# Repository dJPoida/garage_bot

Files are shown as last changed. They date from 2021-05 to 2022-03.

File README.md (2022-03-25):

# GarageBot v1.0
This project adds some form of IoT capability to my existing garage door.

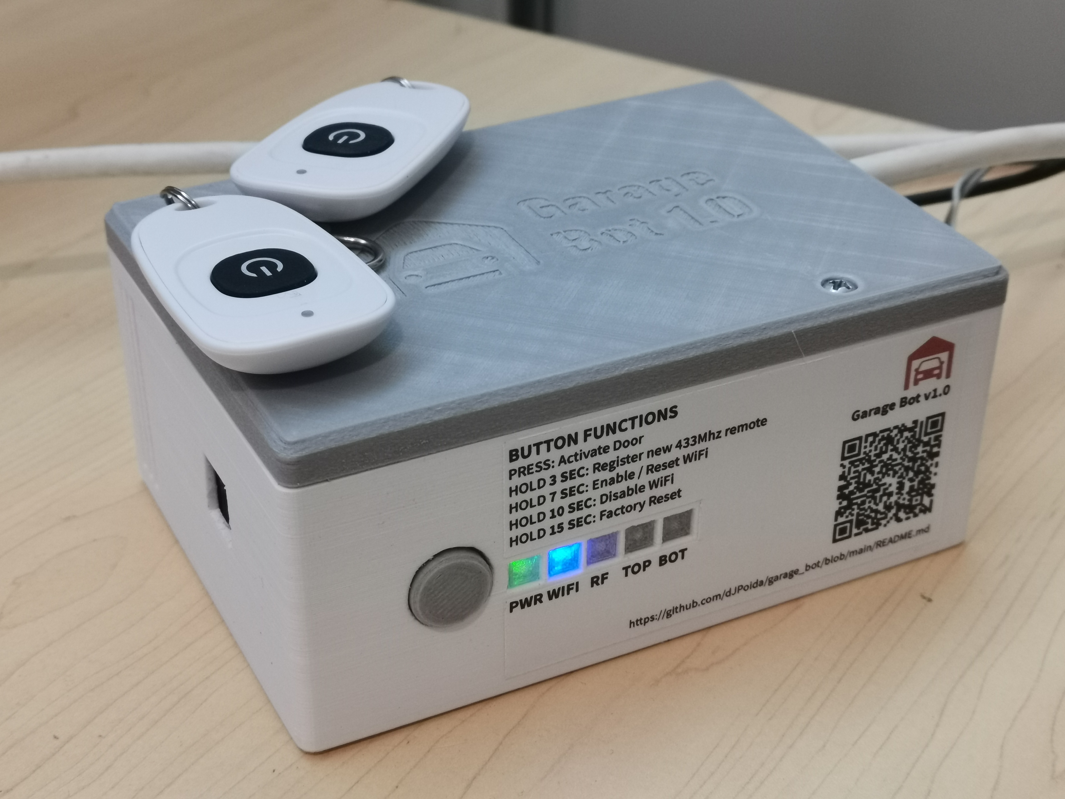
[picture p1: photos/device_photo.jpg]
Device Photo


## Back Story
At the time of creating this project, we were renting our house. This limited our ability to implement smart technology or change out hardware. For over two years our landlord had not supplied us with a second remote control for the garage door, meaning my wife and I had to plan who was going to take the remote with us based on who was likely to be home first. Couple that with frequent incidents of accidentally leaving the garage door open at night, and voila, I had motivation to improve our garage door situation.

## Goals
- End up with a remote control in each car (2x remotes)
- Provide a capability to open / close the garage door from within the house
- Enable Google Home integration
    - Open / Close commands
    - Open / Closed query
- Avoid drastic modification of the garage door to ensure we don't break our lease agreement when it's time to turn over the remote controls

## Getting Started
This is the Link that the QR Code on the device points to. When the new tenant at our property discovers and scans the QR code, they will end up here. Welcome! Read on for instructions on how to operate the device.

## Device Operation

### Front panel button operation
There is only one button on the device. Once pressed, this button will perform a different operation depending on how long it is depressed for:

- **< 1s**: Activate the garage door (open / close / stop)
- **3s**: [Register a new 433Mhz remote](#registering-a-new-remote)
- **7s**: [Enable the WiFi and Reset the WiFi config](#connecting-the-device-to-your-wifi)
- **10s**: [Disable the WiFi and Reset the WiFi config](disabling-the-wifi-functionality)
- **15s**: Perform a full factory reset

### Registering a new Remote

To pair a new 433Mhz remote:

1. Hold down the front panel button on the GarageBot and release it after **3 seconds**.
2. Check that the RF LED (the third LED) is blinking in an *on-on-on-off* pattern. This indicates that the GarageBot is ready to register a new remote. If the Power LED begins to flash in an `on-off` pattern, you have most likely reached the maximum number of 5 registered RF remotes and the device will need to be factory reset to register any new remotes.
3. Hold down the button on the new remote for at least **1s** until all of the lights on the device activate for 3 seconds, indicating a successful registration.

**Important Notes:**
- The remote must use the 433Mhz band
- The remote must use [Amplitude-shift keying (ASK)](https://en.wikipedia.org/wiki/Amplitude-shift_keying) for signal modulation
- You can only register **5 unique remote codes**. Once this limit has been reached, you must factory reset your device to register new remotes.

### Connecting the device to your WiFi
The GarageBot can be connected to your Wifi to either become part of your smart home or to be controlled directly via a web interface.

To connect the GarageBot to your WiFi:

1. Hold down the front panel button on the GarageBot and release it after **7 seconds**.
2. Any existing WiFi details will be cleared and the GarageBot will reboot.
3. Once rebooted, check that the WiFi LED (the second LED) is blinking in an *on-on-on-off* pattern. This indicates that the device is now broadcasting a HotSpot and is ready for WiFi configuration
4. Using a WiFi enabled device (mobile phone, tablet, laptop etc...) scan for available WiFi networks. If you are within range of the GarageBot, you should be able to see the `garagebot` WiFi network.
5. Connect your device to the `garagebot` network. Your device may immediately take you to the GarageBot WiFi configuration page. If not, open a browser and browse to `http://192.168.4.1`.
6. Enter the WiFi SSID and Password of your local WiFi network and click `Submit`.
7. The GarageBot will save the new WiFi details, reboot and attempt to connect to your WiFi network.
8. If the WiFi details were successfully registered and the device was able to connect, the blue WiFi LED (the second LED) will no longer blink and will remain on for as long as the device can access the WiFi network.

Once the GarageBot is connected to your WiFi, you can access it using the url: [http://garagebot.local](http://garagebot.local).

### Disabling the WiFi functionality
If for any reason you want to disable the WiFi functionality of the device, you can do so by following this procedure:

1. Hold down the front panel button on the GarageBot and release it after **10 seconds**.
2. Any existing WiFi details will be cleared, the WiFi functionality will be disabled and the GarageBot will reboot.
3. If the WiFi was successfully disabled, the blue WiFi LED (the second LED) will no longer be illuminated.

### Performing a Factory Reset
If you would like to perform a full factory reset and clear all of the configurations of the device, you can do so by following this procedure:

1. Hold down the front panel button on the GarageBot and release it after **15 seconds**.
2. All of the existing configuration will be cleared and the device will reboot.
2. If the factory reset was successful, all of the LED Lights will light up momentarily just before the reboot of the device.

## LED Lights
There are five LED lights on the GarageBot.

### 1. Power (PWR)
This LED Indicates that the device is on. When holding down the front panel button, this LED will flash in an `on-off` repeating pattern where each `on-off` cycle is 1 second to assist with counting the number of seconds elapsed.

### 2. WiFi
This LED indicates the state of the device's WiFi connection.
- Off: WiFi is not yet enabled
- Solid On: WiFi connected
- Flashing `on-on-on-off`: Broadcasting hot-spot for [WiFi configuration](#connecting-the-device-to-your-wifi)

### 3. Remote Activation (RF)
This LED indicates any RF activity or garage door remote activation.
- Solid On: Activating the legacy Garage Door remote via relay.
- Flashing `on-on-on-off`: [Registering a new remote](#registering-a-new-remote)
- Flashing `on-off`: Error while registering a new remote (most likely the remote registration count of 5 remotes has been exceeded)

### 4. Garage Door Top Sensor (TOP)
This LED indicates whether the top sensor on the garage door can detect the presence of the door.
- Off: Door is detected (i.e. closed)
- On: Door cannot be detected (i.e. open)

### 5. Garage Door Bottom Sensor (BOT)
This LED indicates whether the bottom sensor on the garage door can detect the presence of the door.
- Off: Door is detected (i.e. closed)
- On: Door cannot be detected (i.e. open)

## Home Assistant integration
If you want to integrate with [Home Assistant](https://www.home-assistant.io/) then you can use the `garage_door.yaml` configuration to create a simple `cover` control.

Simply modify `configuration.yaml` and add
```
cover: !include garage_door.yaml
```

## Google Home integration
If you want to integrate the garage door with Google Home for voice commands, follow [JuanMTech's Guide on integrating Google Assistant with Home Assistant](https://www.juanmtech.com/integrate-google-assistant-with-home-assistant-without-a-subscription)

---

## System Design
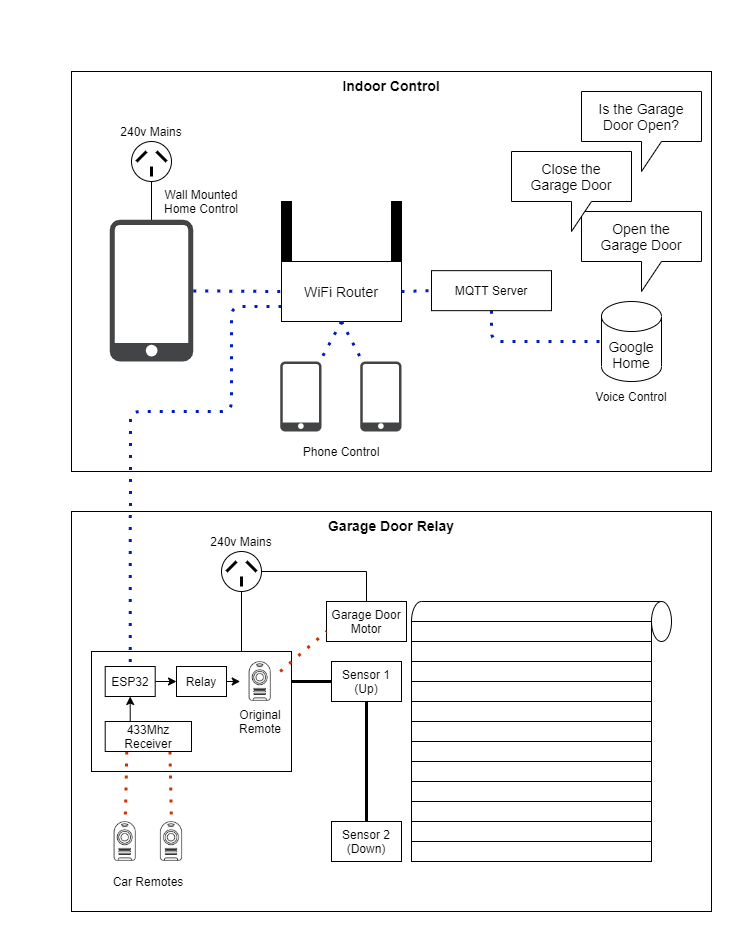
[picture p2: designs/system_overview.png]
System Design


## Schematic
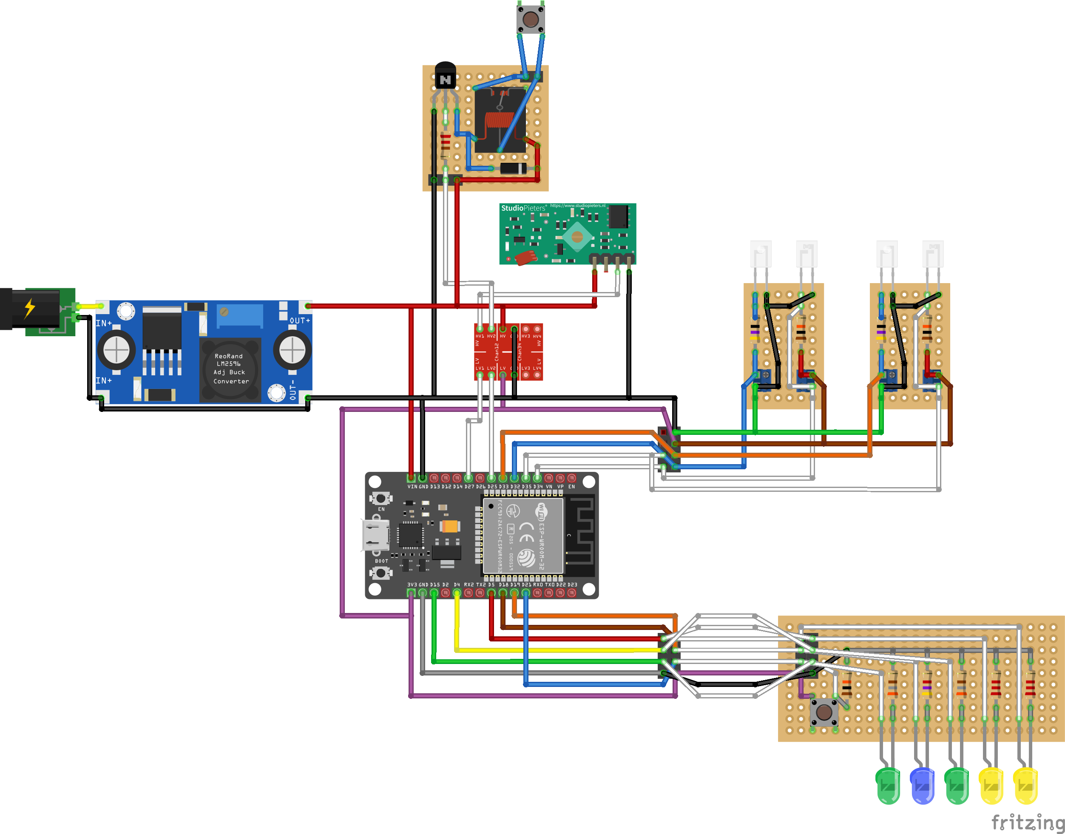
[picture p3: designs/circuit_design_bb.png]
Breadboard Design

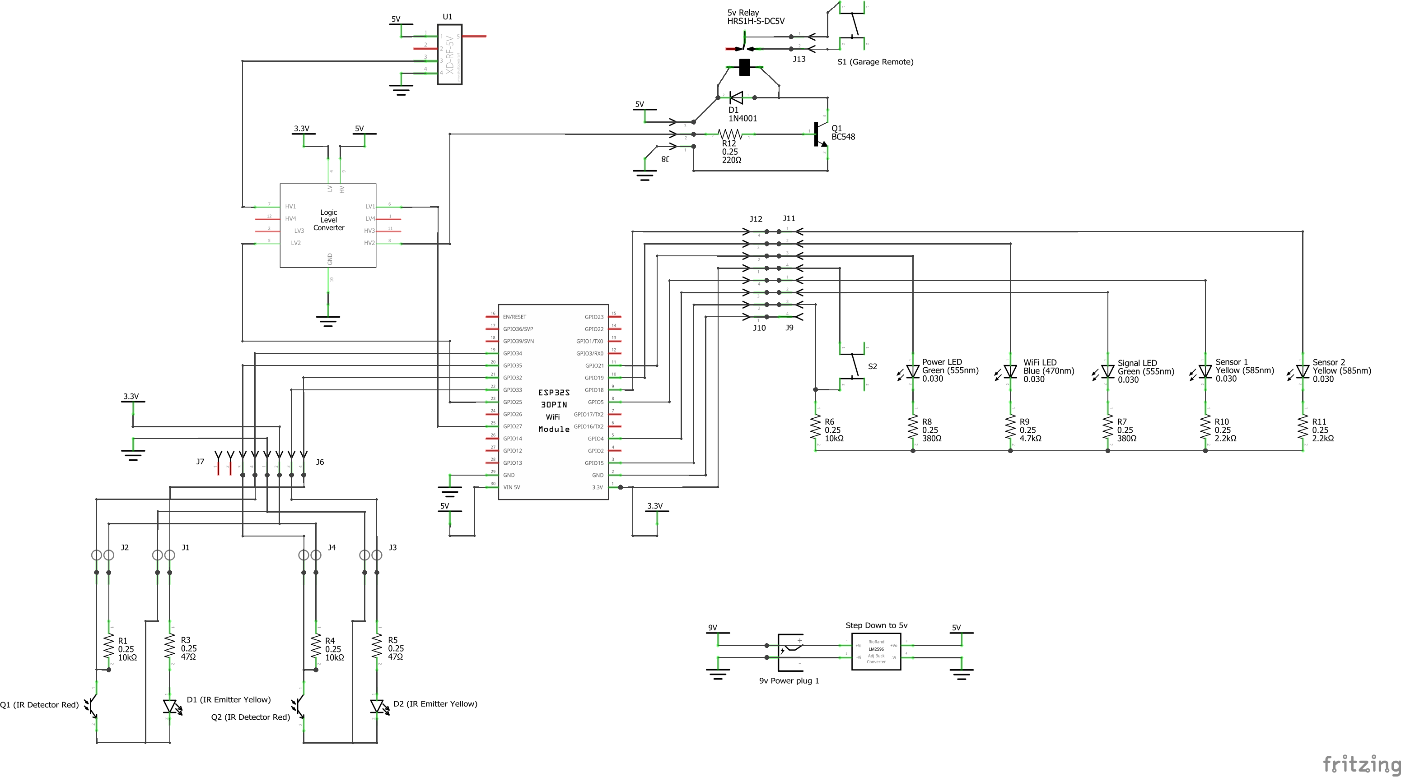
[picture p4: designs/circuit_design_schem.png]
Circuit Design


---

## Contributing

If you want to contribute to this repo, feel free!

### Environments
There are two main environments, the Arduino code that runs the ESP32 and the React web application that runs the WiFi control / setup page.

#### Arduino IDE

#### Visual Studio Code
To work on the Web App you will need the standard [Node.js](https://nodejs.org) kit to develop JS/TS applications.
- The app codebase is located in the `/app` path
- This project was setup using the [yarn package manager](https://yarnpkg.com/), but would still work using NPM if you prefer
- This project uses a custom webpack configuration for build / deploy
```
git clone https://github.com/dJPoida/garage_bot.git
cd app
yarn
yarn start
```
Browse to `http://localhost:3000` to view the app.

**Important note!:** At the time of writing this documentation no device emulator existed. Therefore, the device must be running before the web socket will confirm connection and display the app.

If you want to publish new code to be served from the device, run the build task and the bundle will be created in the `/app/dist` folder and automatically copied into the `/arduino/garage_bot/data` folder for upload using the ESP Sketch Data Upload utility to the device SPIFFS.

```
yarn build
```

---

## Developer TODO
- REST API
    - Provide access to activate Virtual Buttons from an HTTP POST endpoint (perhaps add credentials)
- Documentation
    - Provide a BOM so people can build this themselves
    - Improve CAD and Schematic documentation
    - Improve contribution documentation
        - Describe system dependencies for environments
        - Provide device emulation documentation
- Create a Device Emulator for web app development

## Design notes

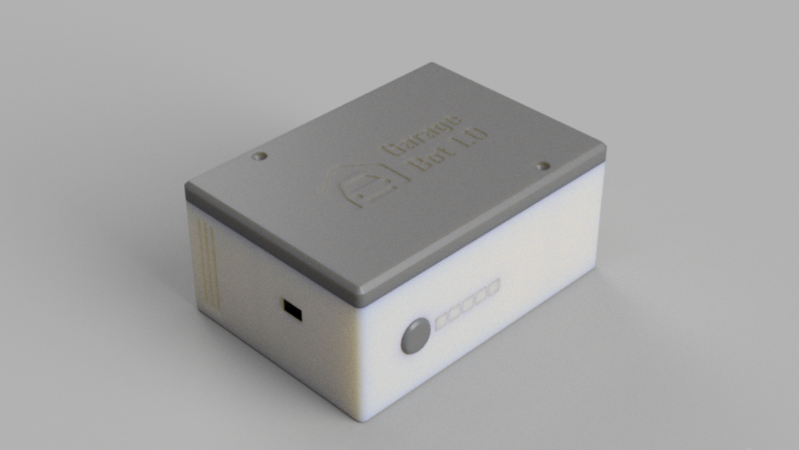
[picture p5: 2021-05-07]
cad/images/Enclosure - Full.png

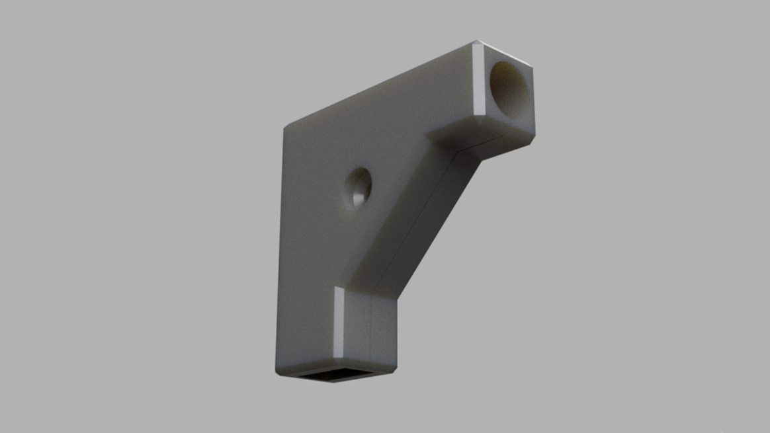
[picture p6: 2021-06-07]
cad/images/Cable L Clamp.png

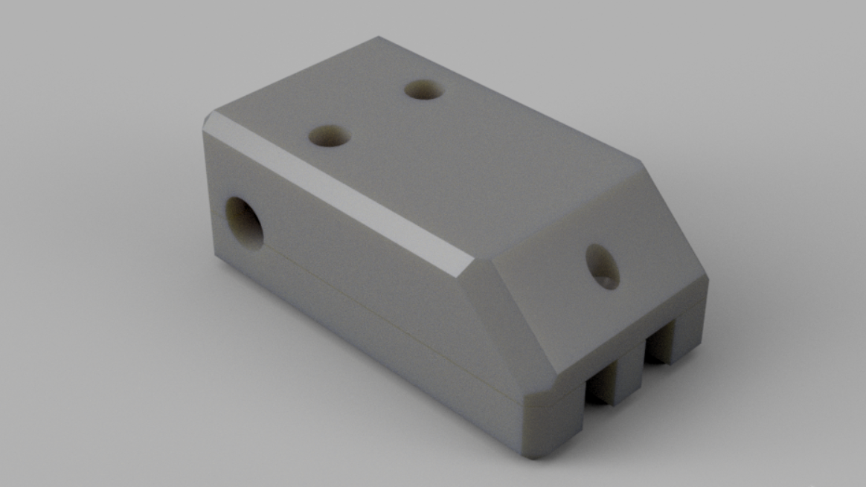
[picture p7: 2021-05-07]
cad/images/Sensor.png

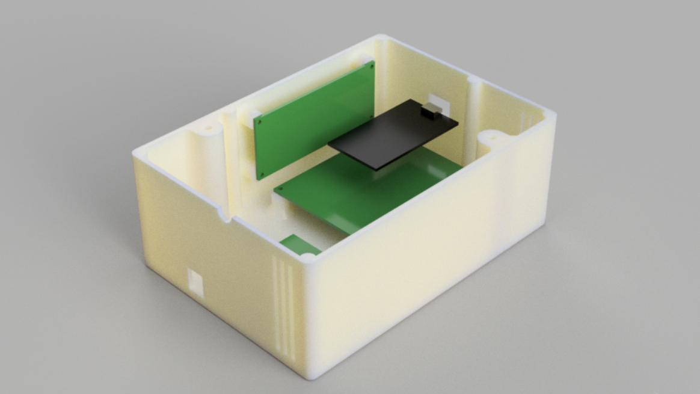
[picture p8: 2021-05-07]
cad/images/Enclosure - Lid Off.png

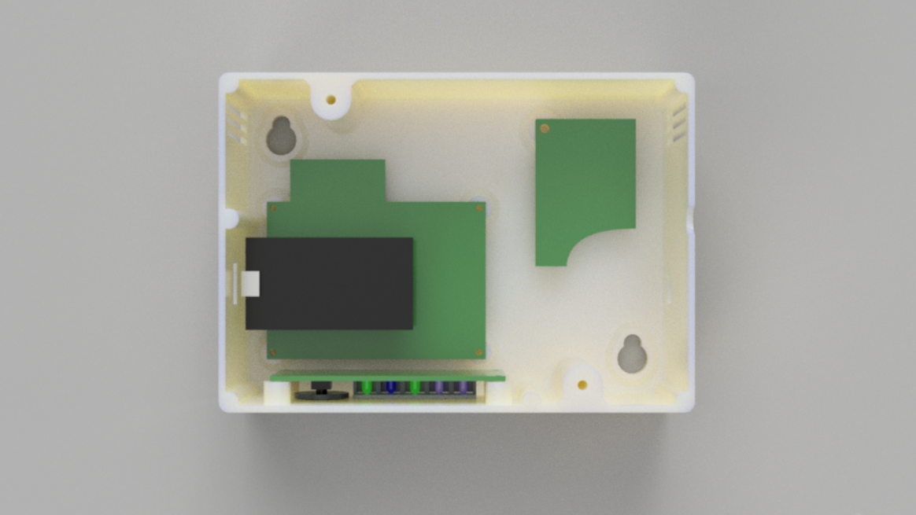
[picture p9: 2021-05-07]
cad/images/Enclosure - Top Down.png

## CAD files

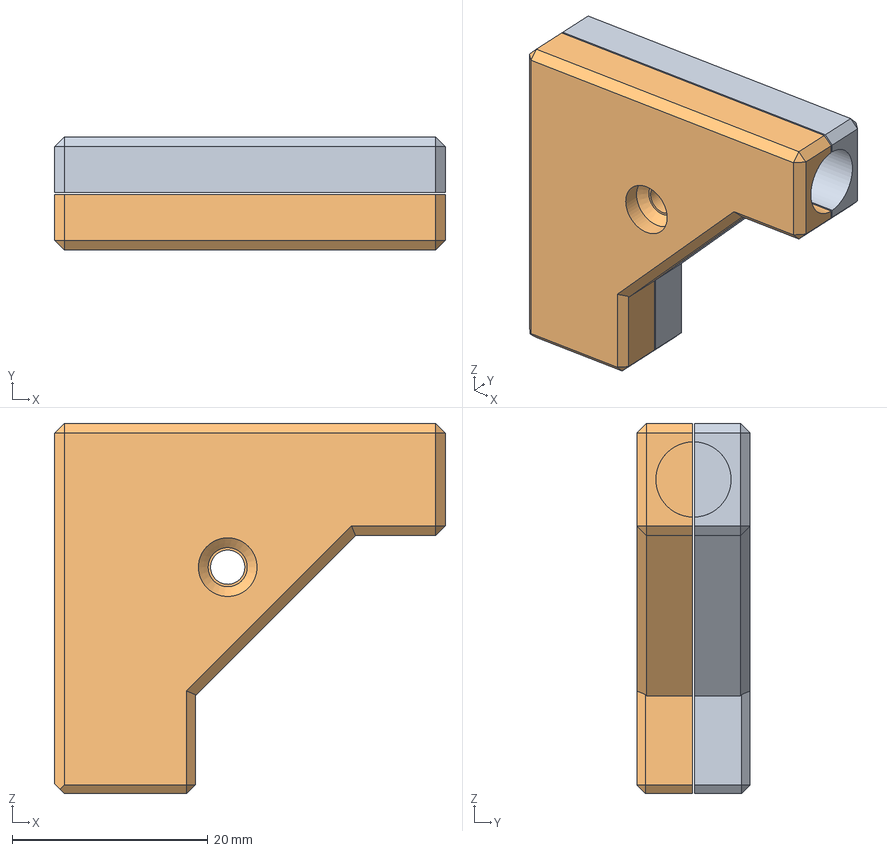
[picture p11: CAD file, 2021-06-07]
cad/step/Cable L Clamp.step
40.0 x 11.6 x 37.9 mm

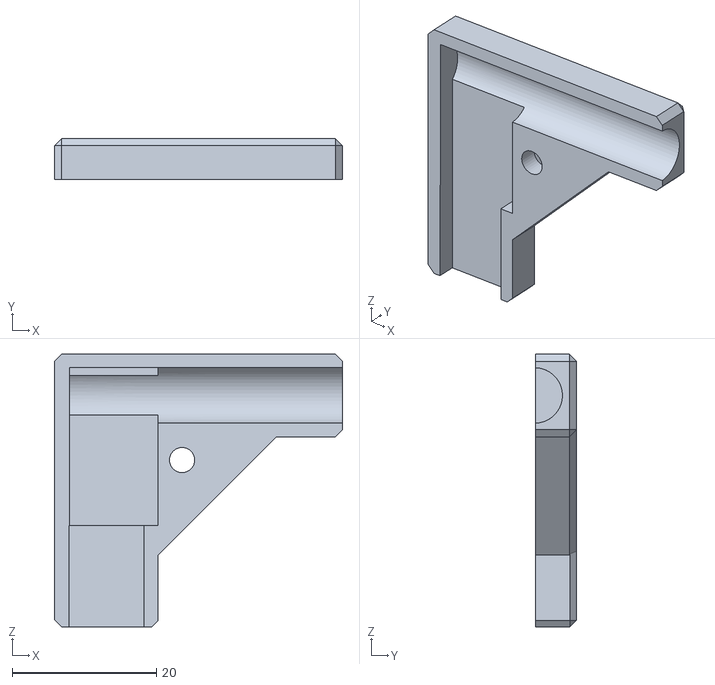
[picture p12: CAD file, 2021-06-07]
cad/stl/Cable L Clamp - A.stl
40.0 x 5.70 x 37.9

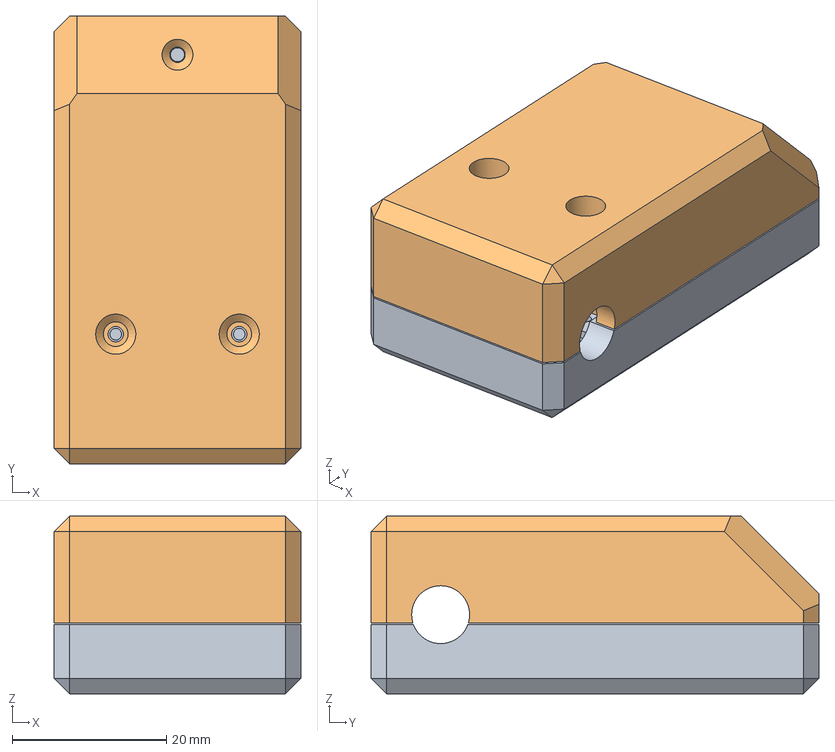
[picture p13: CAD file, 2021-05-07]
cad/step/Sensor - 2 Holes.step
32.0 x 58.0 x 23.0 mm
Base
Lid

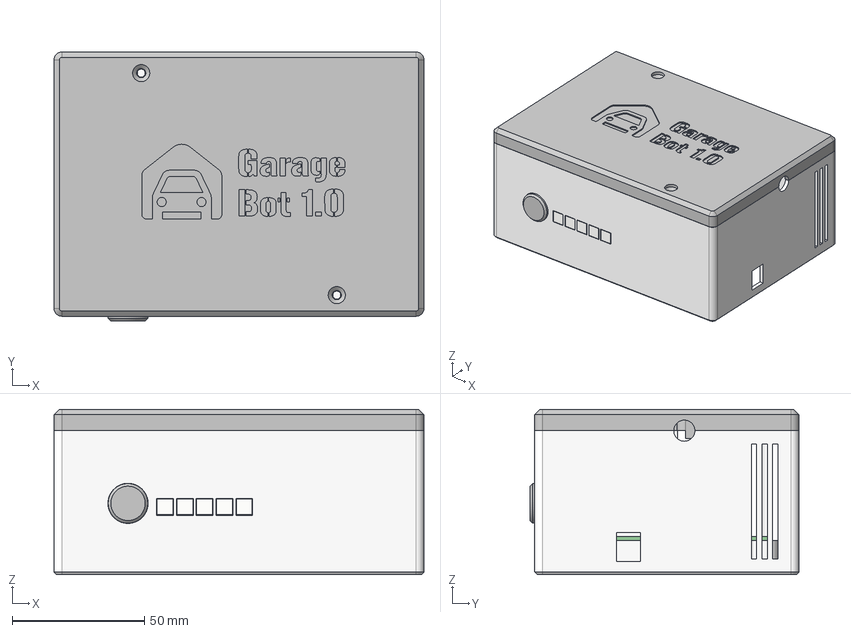
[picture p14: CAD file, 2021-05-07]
cad/step/Enclosure.step
140.0 x 101.8 x 62.6 mm
Enclosure Base
Enclosure Lid
Button
LED Separator
LED Diffuser
OriginalRemote
Main Board
LED Panel

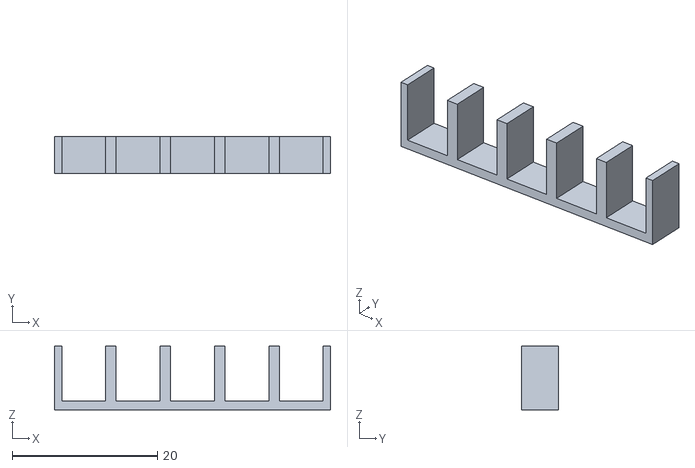
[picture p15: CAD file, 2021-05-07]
cad/stl/LED Separator.stl
38.0 x 5.10 x 8.80

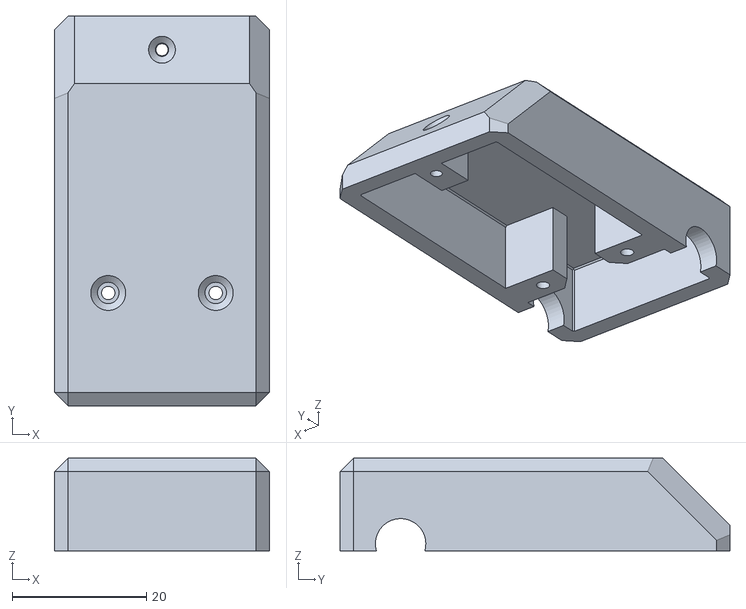
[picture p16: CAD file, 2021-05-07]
cad/stl/Sensor - 2 Holes - Lid.stl
32.0 x 58.0 x 13.8

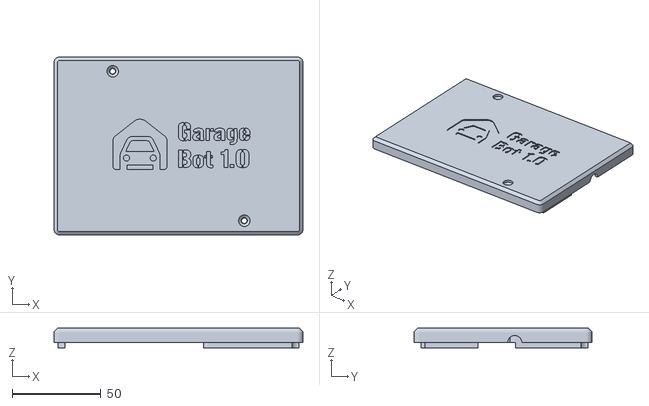
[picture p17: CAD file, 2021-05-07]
cad/stl/Enclosure - Lid.stl
140.0 x 100.0 x 11.0

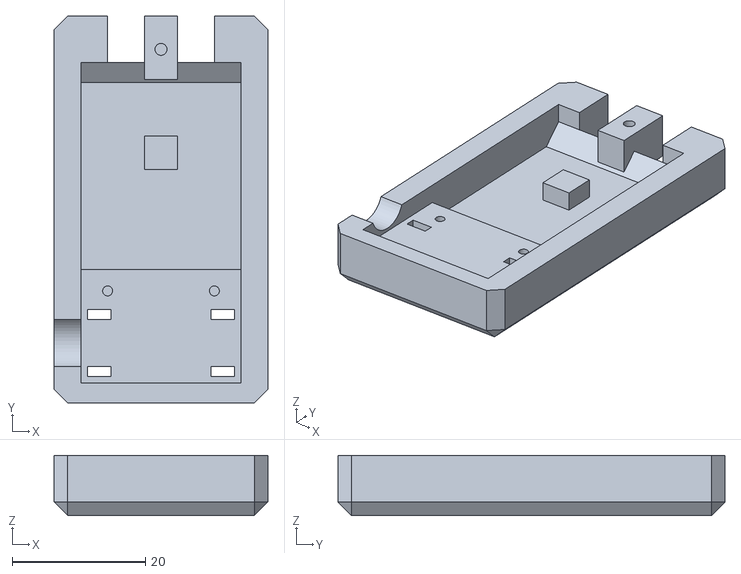
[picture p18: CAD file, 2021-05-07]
cad/stl/Sensor - 1 Hole - Base.stl
32.0 x 58.0 x 9.00

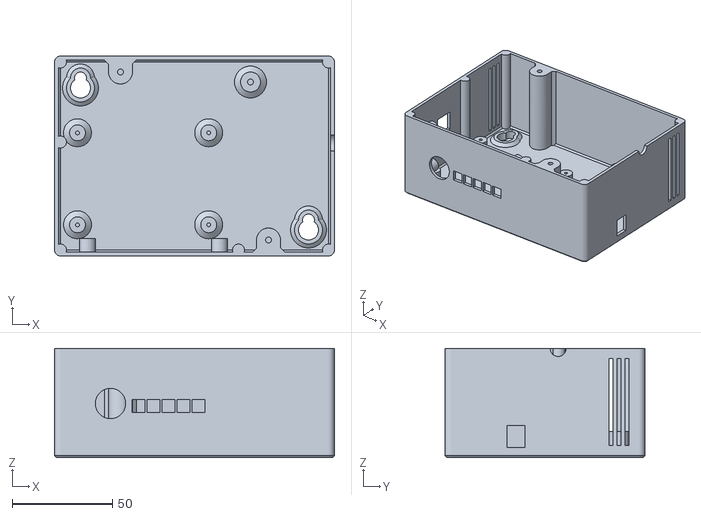
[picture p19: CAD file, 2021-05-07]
cad/stl/Enclosure - Base.stl
140.0 x 100.0 x 54.5

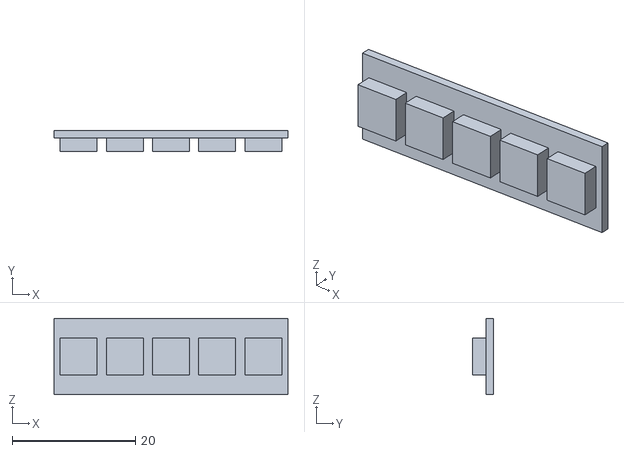
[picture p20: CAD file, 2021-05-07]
cad/stl/LED Diffuser.stl
38.0 x 3.40 x 12.4

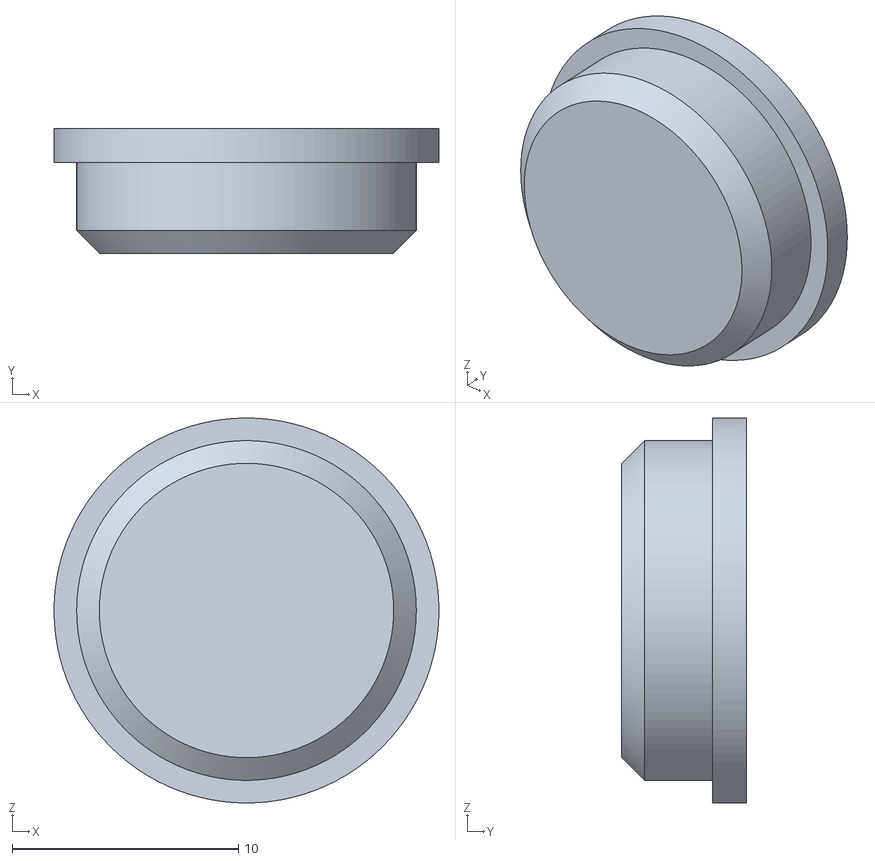
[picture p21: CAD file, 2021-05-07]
cad/stl/Button.stl
17.0 x 5.50 x 17.0

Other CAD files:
cad/stl/Cable L Clamp - B.stl
cad/step/Sensor - 1 Hole.step
cad/stl/Sensor - 2 Holes - Base.stl
cad/stl/Sensor - 1 Hole - Lid.stl

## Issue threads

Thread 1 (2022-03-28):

Device Hostname not broadcasting to network devices

dJPoida, 2022-03-28:
Due to a limitation in the ESP32 Arduino libraries, there appears to be a problem broadcasting the Device name to network listeners.

Without this capability, the device is difficult to identify in routers etc...

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

This did originally work, but there's an outstanding issue in the ESP library: [WiFi.localIP() returns 255.255.255.255 after connect #4732](https://github.com/espressif/arduino-esp32/issues/4732) which could only be resolved by removing the workaround in this issue: [Hostname not sent via DHCP request #2537](https://github.com/espressif/arduino-esp32/issues/4732).

Commented out the line that makes this work in `wifiEngine.cpp` until the IPAddress issue can be resolved:
```
      // Removed to fix issue with ip address resolving as 255.255.255.255 and causing other network errors
      // WiFi.config(INADDR_NONE, INADDR_NONE, INADDR_NONE, INADDR_NONE);
```

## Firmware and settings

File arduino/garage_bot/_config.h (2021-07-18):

/*============================================================================*\
 * Garage Bot - Config
 * Peter Eldred 2021-04
 * 
 * All of the system config goes here
\*============================================================================*/
#ifndef CONFIG_H
#define CONFIG_H

#include "Arduino.h"

#define FIRMWARE_VERSION "0.0.5"

// Comment out this line to remove serial debug from all files
// #define SERIAL_DEBUG

// The five LEDs on the front panel
#define PIN_LED_POWER 21
#define PIN_LED_WIFI 19
#define PIN_LED_REPEATER 4
#define PIN_LED_TOP_SENSOR 5
#define PIN_LED_BOTTOM_SENSOR 18

// The button on the front panel
#define PIN_BTN_FRONT_PANEL 15

// The RF Data Receive Pin
#define PIN_RF_RECEIVE 27

// The Remote Repeater Relay Activation Pin
#define PIN_REMOTE_REPEATER 26

// A delay (ms) to wait to prevent phantom button presses
#define BTN_DEBOUNCE_DELAY 25      

// Anything below this duration is considered a "simple" activate door press
#define BTN_ACTIVATE_DOOR_DURATION 1000

// Anything above this duration is considered a "Register an RF Remote" request
#define BTN_REGISTER_REMOTE_DURATION 3000

// Anything above this duration is considered a "Reset Wifi" request
#define BTN_RESET_WIFI_DURATION 7000

// Anything above this duration is considered a "Disable Wifi" request
#define BTN_DISABLE_WIFI_DURATION 10000

// Anything above this duration is considered a "Factory Reset"
#define BTN_FACTORY_RESET_DURATION 15000

// The garage door sensor pins
#define PIN_SENSOR_TOP_EMITTER 32
#define PIN_SENSOR_TOP_RECEIVER 34
#define PIN_SENSOR_BOTTOM_EMITTER 33
#define PIN_SENSOR_BOTTOM_RECEIVER 35

// The time between reads of the IR Sensors (ms)
#define SENSOR_IR_READ_DELAY 100

// The number of readings to use to average out the value
#define SENSOR_IR_SMOOTHING_READING_COUNT 20

// The number of milliseconds to wait in between sensor data broadcast to the connected socket clients
#define SENSOR_BROADCAST_INTERVAL 1000

// The SSID and network domain name when the device is running in Access Point mode
#define AP_SSID "garagebot"

// The port that the web server is served on.
#define WEB_SERVER_PORT 80          

// How often the WiFi and MQTT clients should attempt to re-connect when disconnected
#define RECONNECT_INTERVAL 30000

// How many milliseconds for each interval/tick in the LED timer
#define LED_TIMER_CYCLE_MS 125

// How many milliseconds the remote repeater should "hold down the garage remote button" for
#define REMOTE_REPEATER_DURATION_MS 1000

// How many milliseconds between RF Remote button presses represent a "separate" button press
#define RF_REMOTE_BUTTON_PRESS_SEPERAION 500

// How many consecutive successful RF receipts are required when registering a new remote
#define REMOTE_CONSECUTIVE_CODES_FOR_REGISTRATION 10

// The maximum number of bytes we can expect to send to the client
#define MAX_SOCKET_SERVER_MESSAGE_SIZE 1024

// The maximum number of bytes we can expect to received from the client
#define MAX_SOCKET_CLIENT_MESSAGE_SIZE 256

// The maximum number of concurrent socket connections to accept
#define MAX_SOCKET_CONNECTIONS 10

// The maximum size of the config file in bytes
#define CONFIG_FILE_MAX_SIZE 2048

// When assuming a door state - ignore sensors for this duration
#define ASSUMED_DOOR_STATE_EXPIRY 5000

// Defaults for some config values
#define DEFAULT_IR_THRESHOLD 150
#define DEFAULT_CONFIG_MDNS_NAME "garagebot"
#define DEFAULT_CONFIG_DEVICE_NAME "GarageBot"
#define DEFAULT_CONFIG_MQTT_BROKER_PORT 1883
#define DEFAULT_CONFIG_MQTT_DEVICE_ID "Garage_Bot"
#define DEFAULT_CONFIG_MQTT_DEVICE_COMMAND_TOPIC "garage/door/command"
#define DEFAULT_CONFIG_MQTT_DEVICE_STATE_TOPIC "garage/door/state"

/**
 * Config struct for storing and loading data from the SPIFFS partition
 */
struct Config {
  // This flag is set when the config is being updated and is referenced to prevent some controllers from running partially configured
  bool updating_config                      = false;

  // The name to use in the mdns address that clients can use to connect to the device without the IP (i.e. http://garagebot.local)
  String mdns_name                          = DEFAULT_CONFIG_MDNS_NAME;

  // The device name to display to other devices on the network and in the app
  String device_name                        = DEFAULT_CONFIG_DEVICE_NAME;
  
  // Whether WiFi is enabled
  bool wifi_enabled                         = false;
  
  // The SSID of the wifi network that the garage bot is configured to connect to
  String wifi_ssid                          = "";
  
  // The Password of the wifi network that the garage bot is configured to connect to
  String wifi_password                      = "";
  
  // Whether the device should attempt to integrate with an MQTT broker
  bool mqtt_enabled                         = false;
  
  // The IP address of the MQTT Broker
  String mqtt_broker_address                = "";

  // The MQTT Broker Port Number
  unsigned int mqtt_broker_port             = DEFAULT_CONFIG_MQTT_BROKER_PORT;

  // The Device ID to use when connecting to the MQTT Broker
  String mqtt_device_id                     = DEFAULT_CONFIG_MQTT_DEVICE_ID;
  
  // The username when connecting to the MQTT broker
  String mqtt_username                      = "";

  // The password when connecting to the MQTT broker
  String mqtt_password                      = "";
  
  // The MQTT topic used for communicating instructions (open / close etc)
  String mqtt_command_topic                 = DEFAULT_CONFIG_MQTT_DEVICE_COMMAND_TOPIC;
  
  // The MQTT topic used for communicating the state of the door (opened / closed / etc)
  String mqtt_state_topic                   = DEFAULT_CONFIG_MQTT_DEVICE_STATE_TOPIC;
  
  // The number of registered RF remote codes (5 Max)
  byte stored_rf_code_count                 = 0;
  
  // 5 RF codes can be stored
  unsigned long rf_codes[5]                 = {0, 0, 0, 0, 0};
  
  // The threshold for detection for the Top IR Sensor  
  unsigned int top_ir_sensor_threshold      = DEFAULT_IR_THRESHOLD;

  // The threshold for detection for the Bottom IR Sensor  
  unsigned int bottom_ir_sensor_threshold   = DEFAULT_IR_THRESHOLD;
};

extern Config config;

/**
 * WebSocket message definitions for sending / receiving data from connected clients
 * These need to be kept in sync with the `socket-server-message.const.ts` and  
 * `socket-client-message.const.ts` in the `app` website code
 */
#define SOCKET_CLIENT_MESSAGE_BUTTON_PRESS "BP"
#define SOCKET_CLIENT_MESSAGE_SET_SENSOR_THRESHOLD "ST"
#define SOCKET_CLIENT_MESSAGE_REBOOT "RB"
#define SOCKET_CLIENT_MESSAGE_FORGET_WIFI "FW"
#define SOCKET_CLIENT_MESSAGE_RESET_TO_FACTORY_DEFAULTS "RF"
#define SOCKET_SERVER_MESSAGE_STATUS_CHANGE "SC"
#define SOCKET_SERVER_MESSAGE_CONFIG_CHANGE "CC"
#define SOCKET_SERVER_MESSAGE_SENSOR_DATA "SD"
#define SOCKET_SERVER_MESSAGE_REBOOTING "RB"

#endif

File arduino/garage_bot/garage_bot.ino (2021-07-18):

/*============================================================================*\
 * Garage Bot
 * Author: Peter Eldred
 * Date: 2021-04
 * GitHub: https://github.com/dJPoida/garage_bot
 * Description: The Garage Bot repeats the RF signal of my legacy garage door
 *              remote control and exposes the state of the door as well as
 *              activation controls to a smart home via an MQTT server.
 * 
 * Hardware
 *  - ESP32 Dev Module (30 Pin)
 *    - CPU Frequency: 240Mhz
 *    - Flash Frequency: 80Mhz
 *    - Partition Scheme: Default 4MB with SPIFFS (1.2MB APP / 1.5MB SPIFFS)
 * 
 * Dependencies:
 *  - Arduino ESP32 File System Uploader (https://github.com/lorol/arduino-esp32fs-plugin)
 *  - Async TCP Library for ESP32 Arduino (https://github.com/me-no-dev/AsyncTCP)
 *  - ESP Async Web Server (https://github.com/me-no-dev/ESPAsyncWebServer)
 *  - RCSwitch for 433mhz Receiver (https://github.com/sui77/rc-switch)
 *  - PubSubClient for MQTT Messaging (https://github.com/knolleary/pubsubclient)
\*============================================================================*/


/**
 * Protection - Prevent this code from running on anything other than an ESP32
 */
#ifndef ESP32
#error This code is designed to run on ESP32 platform, not Arduino nor ESP8266! Please check your Tools->Board setting.
#endif


/**
 * Includes
 */
#include "DNSServer.h"
#include "ESPAsyncWebServer.h"
#include "AsyncTCP.h"
#include "_config.h"
#include "botFS.h"
#include "botLED.h"
#include "botButton.h"
#include "ledTimer.h"
#include "wifiEngine.h"
#include "irsensor.h"
#include "rfReceiver.h"
#include "remoteRepeater.h"
#include "doorControl.h"
#include "mqttClient.h"
#include "otaUpdateManager.h"
#include "reboot.h"


/**
 * Global Variables
 */
const char* firmwareVersion = FIRMWARE_VERSION;                           // Firmware Version
AsyncWebServer webServer(WEB_SERVER_PORT);                                // The Web Server for serving the control code
AsyncWebSocket webSocket("/ws");                                          // The Web Socket for realtime comms with the client application
DNSServer dnsServer;                                                      // A DNS Server for use when in Access Point mode
Config config;                                                            // The configuration struct for storing and reading from LITTLEFS
BotFS botFS = BotFS();                                                    // A File System Wrapper for simplifying LITTLEFS interaction
IRSensor topIRSensor = IRSensor("TOP");                                   // The Top IR Sensor
IRSensor bottomIRSensor = IRSensor("BOTTOM");                             // The Bottom IR Sensor
BotLED powerLED = BotLED(PIN_LED_POWER, "Power");                         // The Power LED
BotLED wiFiLED = BotLED(PIN_LED_WIFI, "WiFi");                            // The WiFi LED
BotLED repeaterLED = BotLED(PIN_LED_REPEATER, "Repeater");                // The Garage Remoter Repeater Activation LED
BotLED topSensorLED = BotLED(PIN_LED_TOP_SENSOR, "Top Sensor");           // The Top Sensor LED
BotLED bottomSensorLED = BotLED(PIN_LED_BOTTOM_SENSOR, "Bottom Sensor");  // The Top Sensor LED
BotButton panelButton = BotButton(PIN_BTN_FRONT_PANEL, "Front Panel");    // The Front Panel Button
RFReceiver rfReceiver = RFReceiver();                                     // The RF Receiver for the remote controls
RemoteRepeater remoteRepeater = RemoteRepeater();                         // The object responsible for triggering the original garage remote
DoorControl doorControl = DoorControl();                                  // The object that manages the logical state of the door (open / closed / opening / closing)
LEDTimer ledTimer = LEDTimer();                                           // A Timer to help with the flashing LEDs
MQTTClient mqttClient = MQTTClient();                                     // The client which manages MQTT broadcasts and subscriptions
WiFiEngine wifiEngine = WiFiEngine();                                     // The Garage Bot's WiFi engine
WiFiClient espClient;                                                     // Used by the MQTT PubSubClient
PubSubClient pubSubClient = PubSubClient(espClient);                      // The MQTT PubSubClient
OTAUpdateManager otaUpdateManager = OTAUpdateManager();                   // The Over The Air (OTA) update manager

bool inError = false;                                                     // Whether the device is in an error state

/**
 * Setup
 */
void setup() {
  // Serial Initialisation
  #ifdef SERIAL_DEBUG
  Serial.begin(9600);
  Serial.println("\n==============================");
  Serial.print("\nGarage Bot v");
  Serial.println(firmwareVersion);
  Serial.println("Author: Peter Eldred (aka dJPoida)");
  Serial.println("https://github.com/dJPoida/garage_bot");
  Serial.println("\n==============================");
  Serial.println();
  #endif

  // LEDs
  powerLED.init(HIGH, LED_SOLID);
  wiFiLED.init(LOW, LED_SOLID);
  repeaterLED.init(LOW, LED_SOLID);
  topSensorLED.init(LOW, LED_SOLID);
  bottomSensorLED.init(LOW, LED_SOLID);

  // Initialise the BotFS
  if (!botFS.init()) {
    // Failed to initialise the File System. Oh well. Bail.
    generalErrorOccurred("\n\nFAILED TO INITIALIZE THE FILE SYSTEM (LITTLEFS). HALTED!");

    return;
  }

  // Sensors
  topIRSensor.init(PIN_SENSOR_TOP_EMITTER, PIN_SENSOR_TOP_RECEIVER, config.top_ir_sensor_threshold);
  topIRSensor.onChange = topSensorChanged;
  bottomIRSensor.init(PIN_SENSOR_BOTTOM_EMITTER, PIN_SENSOR_BOTTOM_RECEIVER, config.bottom_ir_sensor_threshold);
  bottomIRSensor.onChange = bottomSensorChanged;

  // Initialise the WiFi Engine (if enabled)
  // This will automatically attempt to connect to a pre-configured
  // WiFi hotspot and if unable to do so will broadcast an Access Point
  if (config.wifi_enabled && !wifiEngine.init(&webServer, &webSocket, &dnsServer, &topIRSensor, &bottomIRSensor)) {
    // Failed to initialise the WiFi hotspot. Oh well. Bail.
    generalErrorOccurred("\n\nFAILED TO INITIALIZE THE WIFI ENGINE. HALTED!");
    return;
  }

  // Buttons
  panelButton.init();
  panelButton.onPress = panelButtonPressed;
  panelButton.onReleased = panelButtonReleased;

  // Flash Timer
  ledTimer.init();
  ledTimer.onTimer = updateLEDFlashes;

  // RF receiver
  rfReceiver.init();
  rfReceiver.onButtonPress = rfReceiverButtonPressed;
  rfReceiver.onModeChanged = rfReceiverModeChanged;
  rfReceiver.onError = generalErrorOccurred;

  // Remote Repeater
  remoteRepeater.init(PIN_REMOTE_REPEATER);
  remoteRepeater.onChange = remoteRepeaterActivationChanged;

  // Door Control
  doorControl.init();
  doorControl.onStateChange = doorControlStateChanged;

  if (config.wifi_enabled) {
    // If the wifi engine is in access point mode
    if (wifiEngine.wifiEngineMode == WEM_AP) {
      // Put the WiFi LED in flash mode if it is in Access Point mode
      wiFiLED.setMode(LED_FLASH_REGISTER);
    } 
    
    // IF the wifi engine is in regular mode
    else {
      // Initialise the OTA manager
      otaUpdateManager.init();

      // Initialise the MQTT Client
      if (config.mqtt_enabled) {
        mqttClient.init(&pubSubClient);
        mqttClient.onStateChange = handleMQTTStateChanged;
      }

      // Listen to changes in the WiFi client's connectivity
      wifiEngine.onConnectedChanged = handleWiFiConnectedChanged;
      wifiEngine.onVirtualButtonPressed = handleVirtualButtonPressed;
      handleWiFiConnectedChanged(wifiEngine.connected);

      // Allow incoming websocket connections
      wifiEngine.allowIncomingWebSockets();
    }
  }

  // All done
  #ifdef SERIAL_DEBUG
  Serial.println("\nInitialisation Complete.\n==============================");
  Serial.println();
  #endif
}


/**
 * Main Loop
 */
void loop() {
  if (!inError) {
    unsigned long currentMillis = millis();

    // Run each of the delegated object controllers
    if (!config.updating_config) {
      topIRSensor.run(currentMillis);
      bottomIRSensor.run(currentMillis);
      ledTimer.run(currentMillis);
      panelButton.run(currentMillis);
      rfReceiver.run(currentMillis);
      remoteRepeater.run(currentMillis);
      doorControl.run(currentMillis);
    }
    
    // Wifi functions
    if (config.wifi_enabled) {
      // The OTAUpdateManager processes requests to update the software
      if (!config.updating_config) {
        otaUpdateManager.run(currentMillis);
      }

      // The wifi engine.run will process Access Point requests and check and manage for wifi disconnections
      // This also sends sensor data to any connected socket clients
      wifiEngine.run(currentMillis);
    
      // Only run the MQTT loop if the wifi and mqtt services are enabled
      if (!config.updating_config && config.mqtt_enabled) {
        mqttClient.run(currentMillis);
      }
    }

    // Check to see if the reboot flag has been tripped
    checkReboot();
  }
}


/**
 * Fired when the top sensor changes state
 * 
 * @param detected whether an object is being detected by the sensor
 */
void topSensorChanged(SensorDetectionState detected) {
  topSensorLED.setState(detected == SENSOR_NOT_DETECTED);

  doorControl.setSensorStates(detected, bottomIRSensor.detected);

  #ifdef SERIAL_DEBUG
  Serial.print("Top: ");
  Serial.println(detected == SENSOR_DETECTED ? "Detected" : "Not Detected");
  #endif
}


/**
 * Fired when the bottom sensor changes state
 * 
 * @param detected whether an object is being detected by the sensor
 */
void bottomSensorChanged(SensorDetectionState detected) {
  bottomSensorLED.setState(detected == SENSOR_NOT_DETECTED);

  doorControl.setSensorStates(topIRSensor.detected, detected);

  #ifdef SERIAL_DEBUG
  Serial.print("Bottom: ");
  Serial.println(detected == SENSOR_DETECTED ? "Detected" : "Not Detected");
  #endif
}


/**
 * Fired when the state of the remote repeater activation changes
 * 
 * @param activated whether the remote repeater is activating or not
 */
void remoteRepeaterActivationChanged(bool activated) {
  repeaterLED.setState(activated);

  #ifdef SERIAL_DEBUG
  Serial.print("Remote Repeater Active: ");
  Serial.println(activated);
  #endif
}


/**
 * Fired when the RF Receiver detects a button press
 * 
 * @param down whether the remote button is being "pressed"
 */
void rfReceiverButtonPressed(bool down) {
  #ifdef SERIAL_DEBUG
  Serial.print("Remote Button ");
  #endif
  
  if (down) {
    #ifdef SERIAL_DEBUG
    Serial.println("Pressed");
    #endif

    // Activate the garage door control
    doorControl.activate();
  } else {
    #ifdef SERIAL_DEBUG
    Serial.println("Released");
    #endif
  }
}


/**
 * Fired when the RF Receiver changes mode.
 * Only really used to change how the RF Receiver LED flashes
 */
void rfReceiverModeChanged(RFReceiverMode newMode) {
  switch (newMode) {
    case RF_RECEIVER_MODE_REGISTERING:
      repeaterLED.setMode(LED_FLASH_REGISTER);
      break;
    default:
      repeaterLED.setMode(LED_SOLID);
      break;
  }
}


/**
 * Fired whenever an error has occurred for some reason
 */
void generalErrorOccurred(String errorMessage) {
  inError = true;

  powerLED.set(true, LED_FLASH);
  wiFiLED.set(true, LED_FLASH);
  repeaterLED.set(true, LED_FLASH);

  #ifdef SERIAL_DEBUG
  Serial.println("\nGeneral Error Occurred!");
  Serial.println(errorMessage);
  Serial.println("Device Halted");
  #endif
}


/**
 * Fired when the button is pressed
 */
void panelButtonPressed() {
  // To help the user count the number of seconds passed, the Power LED will flash 500ms ON / 500ms OFF
  // for as long as they are holding the button down.
  powerLED.set(true, LED_FLASH);
}


/**
 * Fired when the button is released after one of the pre-defined durations
 * 
 * @param buttonPressType the pre-defined duration the button was pressed for
 */
void panelButtonReleased(ButtonPressType buttonPressType) {
  // The Power LED would have been blinking up until this point. Reset it to a solid ON.
  powerLED.set(true, LED_SOLID);

  switch (buttonPressType) {
    case SIMPLE:
      #ifdef SERIAL_DEBUG
      Serial.println("Simple Button Press Detected");
      #endif
      doorControl.activate();
      break;

    case REGISTER_REMOTE:
      #ifdef SERIAL_DEBUG
      Serial.println("Register Remote Button Press Detected");
      #endif
      rfReceiver.setMode(RF_RECEIVER_MODE_REGISTERING);
      break;

    case RESET_WIFI:
      #ifdef SERIAL_DEBUG
      Serial.println("Wifi Reset Button Press Detected");
      #endif
      // Reset the WiFi config
      botFS.resetWiFiConfig(true);
      break;

    case DISABLE_WIFI:
      #ifdef SERIAL_DEBUG
      Serial.println("Disable Wifi Button Press Detected");
      #endif
      // Disable the WiFi
      botFS.resetWiFiConfig(false);
      break;

    case FACTORY_RESET:
      #ifdef SERIAL_DEBUG
      Serial.println("Factory Reset Button Press Detected");
      #endif
      // Full Factory Reset
      // Turn on ALL the LEDs
      powerLED.set(true);
      wiFiLED.set(true);
      repeaterLED.set(true);
      topSensorLED.set(true);
      bottomSensorLED.set(true);
      delay(3000);
      botFS.factoryReset();
      break;

    default:
      break;
  }
}


/**
 * Fired when the LED Timer is triggered
 */
void updateLEDFlashes() {
  powerLED.nextCycle();
  repeaterLED.nextCycle();
  wiFiLED.nextCycle();
}


/**
 * Fired when the Door Control state changes
 */
void doorControlStateChanged(DoorState newDoorState) {
  // Notify any connected clients of the door state change
  if (config.wifi_enabled) {
    wifiEngine.sendStatusToClients();

    if (config.mqtt_enabled) {
      mqttClient.sendDoorStateToBroker();
    }
  }

  #ifdef SERIAL_DEBUG
  Serial.println(doorControl.getDoorStateAsString());
  #endif
}


/**
 * Fired by the WiFi engine when the connected boolean changes
 */
void handleWiFiConnectedChanged(bool newConnected) {
  // The WiFi engine is now connected to the configured hotspot
  if (newConnected) {
    // Display a solid blue WiFi LED
    wiFiLED.set(true, LED_SOLID);
  } 
  
  // The WiFi engine has lost connection to the configured hotspot
  else {
    // Flash the blue WiFi LED.
    wiFiLED.set(false, LED_FLASH);
  }
}


/**
 * Fired when a virtual button is pressed
 */
void handleVirtualButtonPressed(VirtualButtonType virtualButton) {
  DoorState currentDoorState = doorControl.getDoorState();

  switch (virtualButton) {
    case ACTIVATE:
      #ifdef SERIAL_DEBUG
      Serial.println("Virtual Activate Button Press Detected");
      #endif
      doorControl.activate();
      break;

    case OPEN:
      #ifdef SERIAL_DEBUG
      Serial.println("Virtual Open Button Press Detected");
      #endif
      doorControl.open();
      break;

    case CLOSE:
      #ifdef SERIAL_DEBUG
      Serial.println("Virtual Close Button Press Detected");
      #endif
      doorControl.close();
      break;
  }
}


/**
 * Fired by the MQTT Client when its state changes
 */
void handleMQTTStateChanged(MQTTState newState, String error) {
  #ifdef SERIAL_DEBUG
  Serial.print("MQTT State Changed: ");
  Serial.println(mqttClient.getMQTTStateAsString());
  #endif

  // Notify any connected clients of the MQTT Client state change
  if (config.wifi_enabled) {
    wifiEngine.sendStatusToClients();
  }
}

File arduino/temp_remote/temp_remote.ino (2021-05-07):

#include <RCSwitch.h>

RCSwitch mySwitch = RCSwitch();

void setup() {
 Serial.begin(9600);

 // Transmitter is connected to Arduino Pin #10 
 mySwitch.enableTransmit(2);

 // Optional set pulse length.
 mySwitch.setPulseLength(321);

 // set protocol (default is 1, will work for most outlets)
 // mySwitch.setProtocol(2);

 // Optional set number of transmission repetitions.
 // mySwitch.setRepeatTransmit(15);
}

void loop() {
 mySwitch.send("100000101100100011001000");
 delay(500); 
}

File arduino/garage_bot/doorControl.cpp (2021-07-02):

/*============================================================================*\
 * Garage Bot - doorControl
 * Peter Eldred 2021-05
 * 
 * This class manages the state of the door and ensures that a simple request
 * to trigger the remote will not "double open" the door
\*============================================================================*/

#include "_config.h"
#include "helpers.h"
#include "doorControl.h"
#include "remoteRepeater.h"

/**
 * Constructor
 */
DoorControl::DoorControl(){ }


/**
 * Initialise
 */
void DoorControl::init() {
  #ifdef SERIAL_DEBUG
  Serial.print("Initialising Door Control...");
  #endif

  _doorState = DOORSTATE_UNKNOWN;

  #ifdef SERIAL_DEBUG
  Serial.println(" done.");
  #endif
}


/**
 * Basically press the garage door "activate" button
 */
void DoorControl::activate() {
  remoteRepeater.activate();

  if (_doorState == DOORSTATE_OPENING) {
    setAssumedDoorState(DOORSTATE_CLOSING);
  } else if (_doorState == DOORSTATE_OPEN) {
    setAssumedDoorState(DOORSTATE_CLOSING);
  } else if (_doorState == DOORSTATE_CLOSING) {
    setAssumedDoorState(DOORSTATE_OPENING);
  } else if (_doorState == DOORSTATE_CLOSED) {
    setAssumedDoorState(DOORSTATE_OPENING);
  } else {
    clearAssumedDoorState();
  }
}


/**
 * Open the door (if not already open / opening)
 */
void DoorControl::open() {
  if (_doorState != DOORSTATE_OPEN && _doorState != DOORSTATE_OPENING) {
    remoteRepeater.activate();
    setAssumedDoorState(DOORSTATE_OPENING);
  } else {
    #ifdef SERIAL_DEBUG
    Serial.println("Door already open / opening. Ignoring Close Command");
    #endif
  }
}


/**
 * Close the door
 */
void DoorControl::close() {
  if (_doorState != DOORSTATE_CLOSED && _doorState != DOORSTATE_CLOSING) {
    remoteRepeater.activate();
    setAssumedDoorState(DOORSTATE_CLOSING);
  } else {
    #ifdef SERIAL_DEBUG
    Serial.println("Door already closed / closing. Ignoring Close Command");
    #endif
  }
}


/**
 * When the virtual open / close buttons are pressed, we want to
 * assume that the door is in an opening / closing state until the sensors
 * can confirm or deny that state.
 */
void DoorControl::setAssumedDoorState(DoorState assumedDoorState) {
  // Only doo something if the door state has changed
  if (_doorState != assumedDoorState) {
    _doorState = assumedDoorState;
    _assumedDoorStateSetTime = millis();

    // Notify Listeners
    if (onStateChange) {
      onStateChange(_doorState);
    }
  }
}


/**
 * When the "activate" button is pressed, all bets are off.
 * We no longer know what the assumed door state is and kill any
 * expected door state off and revert to sensor detection
 */
void DoorControl::clearAssumedDoorState() {
  _assumedDoorStateSetTime = 0;

  DoorState oldDoorState = _doorState;

  _calculateDoorStateFromSensors(oldDoorState);

  // Has the door state changed?
  if (oldDoorState != _doorState) {
    if (onStateChange) {
      onStateChange(_doorState);
    }
  }
}


/**
 * Run
 * 
 * @param currentMillis the current milliseconds as passed down from the main loop
 */
void DoorControl::run(unsigned long currentMillis) {
  // Stop assuming the door state and rely on sensors
  if (_assumedDoorStateSetTime > 0 && ((_assumedDoorStateSetTime + ASSUMED_DOOR_STATE_EXPIRY) < currentMillis)) {
    clearAssumedDoorState();
  }
}


/**
 * Set the states of the two sensors used to evaluate the state of the door
 * 
 * @param {SensorDetectionState} topSensor whether the top sensor detects the door
 * @param {SensorDetectionState} bottomSensor whether the bottom sensor detects the door
 */
void DoorControl::setSensorStates(SensorDetectionState topSensor, SensorDetectionState bottomSensor) {
  // Only do something if the states have changes
  if ((topSensor != _topSensor) || (bottomSensor != _bottomSensor)) {
    _topSensor = topSensor;
    _bottomSensor = bottomSensor;

    // Not relying on assumed door state
    if (_assumedDoorStateSetTime == 0) {
      DoorState oldDoorState = _doorState;

      _calculateDoorStateFromSensors(oldDoorState);

      // Has the door state changed?
      if (oldDoorState != _doorState) {
        if (onStateChange) {
          onStateChange(_doorState);
        }
      }
    }
  }
}


/**
 * Getter for the current DoorState
 */
DoorState DoorControl::getDoorState() {
  return _doorState;
}


/**
 * Convert the current door state into a string for transport to the client
 */
String DoorControl::getDoorStateAsString() {
  switch (_doorState) {
    case DOORSTATE_OPEN:
      return F("OPEN");
    case DOORSTATE_CLOSING:
      return F("CLOSING");
    case DOORSTATE_CLOSED:
      return F("CLOSED");
    case DOORSTATE_OPENING:
      return F("OPENING");
    default: 
      return F("UNKNOWN");
  }
}


/**
 * Fired when the door state changes
 */
void DoorControl::_calculateDoorStateFromSensors(DoorState oldDoorState) {
  // Door is open
  if (_topSensor == SENSOR_NOT_DETECTED && _bottomSensor == SENSOR_NOT_DETECTED) {
    _doorState = DOORSTATE_OPEN;
  }

  // Door is closed
  else if (_topSensor == SENSOR_DETECTED && _bottomSensor == SENSOR_DETECTED) {
    _doorState = DOORSTATE_CLOSED;
  }

  // Don't allow transitioning states if we don't know the previous state of the door
  else if (oldDoorState != DOORSTATE_UNKNOWN) {
    if (_doorState == DOORSTATE_OPEN) {
      _doorState = DOORSTATE_CLOSING;
    } else if (_doorState == DOORSTATE_CLOSED) {
      _doorState = DOORSTATE_OPENING;
    }
  }
}

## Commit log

2021-05-18 Web Socket basics connecting
2021-05-19 socket messages working
2021-05-21 Fixed sensors
2021-05-24 Relay config and state to webapp
2021-06-02 Swapped RF receiver to pin D27
    [circuit_design.fzz]
2021-06-04 Using VSCode instead of Arduino IDE
2021-06-12 Client Socket Reconnection Device socket connection counting ESLint and Prettier under control
2021-06-15 more device control for the app
2021-06-18 Added IR Sensor calibration interface
2021-06-25 General fixes and enhanced config
    [_config.h, botFS.cpp, garage_bot.ino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]
2021-06-29 Fixed a whole bunch of config e2e
    [wifiEngine.cpp]
2021-07-16 Debounced RF remote button presses
